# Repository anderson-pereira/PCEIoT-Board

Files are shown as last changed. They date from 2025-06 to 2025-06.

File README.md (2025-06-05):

# PCEIoT-Board V1.1.0

Este repositório contém os arquivos de projeto da placa **PCEIoT V1.1.0**, utilizada como ferramenta didática no curso **Projeto de Circuitos Eletrônicos para IoT**.

Texto alternativo

## Sobre o Curso: Projeto de Circuitos Eletrônicos para IoT

O curso foi concebido para capacitar estudantes de graduação no desenvolvimento de circuitos eletrônicos para aplicações em Internet das Coisas (IoT). O aprendizado abrange desde a **seleção de sensores e componentes** até a **criação e finalização de diagramas esquemáticos** utilizando o software Altium Designer.

Ao longo das aulas, os participantes exploram:

* **Protocolos de comunicação** básicos como I2C, SPI e UART.
* A interpretação de **datasheets** (folhas de dados) dos componentes eletrônicos.
* Habilidades práticas na elaboração de esquemáticos e interfaces para **sensores, botões, LEDs e conectores**.

Com uma abordagem que une teoria e prática, o curso permite a compreensão dos princípios fundamentais do design de circuitos eletrônicos por meio do desenvolvimento de projetos reais, preparando os alunos para os desafios do design de placas de circuito impressos.

## Organização dos Arquivos

Os arquivos do projeto estão estruturados da seguinte forma:

* 📂 `Altium Designer Sources`
    * Contém todos os arquivos fonte (.PcbDoc, .SchDoc, etc.) utilizados no design da PCB no Altium Designer.
* 📄 `Datasheets`
    * Reúne a documentação técnica (datasheets) dos principais componentes eletrônicos empregados na placa.
* 🛠️ `Fabrication and Assembly`
    * Inclui os arquivos de fabricação (Gerbers, NC Drill), esquemáticos em PDF, lista de materiais (BOM - Bill of Materials) e outras informações essenciais para a fabricação e montagem da PCB.

---

### Como Utilizar este Repositório

1.  **Para Estudo:** Explore os esquemáticos e o layout da PCB na pasta `Altium Designer Sources` (requer Altium Designer) ou os PDFs em `Fabrication and Assembly`.
2.  **Para Fabricação:** Utilize os arquivos da pasta `Fabrication and Assembly` para encomendar a fabricação da placa e adquirir os componentes listados na BOM.
3.  **Para Referência:** Consulte os `Datasheets` para entender o funcionamento e as especificações de cada componente.

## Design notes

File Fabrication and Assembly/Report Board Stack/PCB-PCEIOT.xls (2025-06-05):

Board Stack Report
Stack Up |  | Layer Stack
Layer | Board Layer Stack | Name | Material | Thickness | Constant
1 |  | Top Overlay |  | 0mm
2 |  | Top Mask | Solder Resist | 0.03048mm | 3.8
3 |  | Top Copper |  | 0.035mm
4 |  | Dielectric 1 | 7628 | 0.2104mm | 4.4
5 |  | Top Ref |  | 0.0152mm
6 |  | Core | FR-4 | 1.065mm | 4.6
7 |  | Botton Ref |  | 0.0152mm
8 |  | Dielectric 2 | 7628 | 0.2104mm | 4.4
9 |  | Bottom Copper |  | 0.035mm
10 |  | Bottom Mask | Solder Resist | 0.03048mm | 3.8
11 |  | Bottom Overlay |  | 0mm
 | Height : 1.64716mm

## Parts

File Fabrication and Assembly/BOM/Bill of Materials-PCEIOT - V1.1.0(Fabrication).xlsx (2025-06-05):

Quantity | Designator | Comment | Description | Footprint | LibRef
21 | C6, C7, C9, C11, C12, C13, C14, C15, C16, C17, C18, C20, C21, C22, C23, C24, C25, C26, C27, C28, C29 | VJ0603Y104MXJCW1BC | Multilayer Ceramic Capacitor, 0.1 uF, 16 V, ± 20%, X7R, 0603 [1608 Metric] | CAPC0603(1608)100_L | CMP-001-00085-1
17 | R2, R3, R4, R8, R11, R12, R13, R14, R18, R21, R22, R23, R26, R27, R36, R37, R44 | Resistor 10k +/-1% 0603 100 mW | Chip Resistor, 10 KOhm, +/- 1%, 01 W, -55 to 155 degC, 0603 (1608 Metric) | RESC0603(1608)_L | CMP-009-00017-7
6 | R16A, R16B, R16C, R17A, R17B, R17C | ERJ-3EKF1000V | SMD Chip Resistor, 100 Ohm, ï¿½ 1%, 100 mW, 0603 [1608 Metric], Thick Film, Precision | RESC0603(1608)_L | CMP-009-00188-1
5 | R5, R9, R10, R30, R31 | Resistor 0R +/- 5% 0603 100 mW | Chip Resistor, 0 Ohm, 0.1 W, -55 to 155 degC, 0603 (1608 Metric) | RESC0603(1608)_L | CMP-009-00006-6
4 | C1, C4, C5, C19 | VJ0603Y103KXAAC | Multilayer Ceramic Capacitor, 0.01 uF, 50 V, ± 10%, X7R, 0603 [1608 Metric] | CAPC0603(1608)100_L | CMP-001-00084-1
4 | R1, R38, R41, R45 | Resistor 1k +/-1% 0603 100 mW | Chip Resistor, 1 KOhm, +/-1%, 0.1 W, -55 to 155 degC, 0603 (1608 Metric) | RESC0603(1608)_L | CMP-009-00014-6
3 | D2A, D2B, D2C | ASMT-YTB7-0AA02 | LED Tri-Color Blue/Green/Red 469nm/529nm/623nm Chip LED 6-Pin PLCC T/R | FP-PLCC-6-MFG | CMP-007-00036-1
3 | R15A, R15B, R15C | ERJ-3GEYJ301V | Res Thick Film 0603 300 Ohm 5% 1/10W ±200ppm/°C Molded SMD Punched Carrier T/R | RESC0603(1608)_L | CMP-009-00189-1
3 | SW1, SW2, SW3 | FSM4JSMA | Switch Tactile OFF (ON) SPST Round Button Gull Wing 0.05A 12VDC 1.57N SMD Loose Piece | TECO-FSM4JSMA_V | CMP-011-00013-1
2 | C2, C3 | Capacitor 4.7µF +/-20% 10V 0603 | Chip Capacitor, 4.7µF +/-20%, 10V, 0603, Thickness 1 mm | CAPC0603(1608)100_L | CMP-001-00076-4
2 | L1, L2 | BLM21PG331SN1D | IND, Chip Ferrite Bead, 330 Ohm, +/- 25%, 1.5 A, -55 to 125 degC, 0805 (2012 Metric), Tape and Reel | INDC2013X105X50ML20T20 | CMP-006-00000-3
2 | Q1, Q2 | DMN1019USN-7 | N-Channel 12 V 10 mO 50.6 nC SMT Enhancement Mode Mosfet - SC-59 (SOT-23) | FP-SC59-MFG | CMP-013-00035-1
2 | R25, R28 | ERJ-3GEYJ475V | Res Thick Film 0603 4.7M Ohm 5% 0.1W -400ppm/°C to 150ppm/°C Molded SMD Punched Carrier T/R | RESC0603(1608)_L | CMP-009-00185-1
2 | R35, R43 | CRCW06032K20FKEA | SMD Chip Resistor, 2.2 kOhm, ± 1%, 100 mW, 0603 [1608 Metric], Thick Film, General Purpose | RESC0603(1608)_L | CMP-009-00186-1
2 | R39, R40 | Resistor 100k +/-1% 0603 100 mW | Chip Resistor, 100 KOhm, +/- 1%, 0.1 W, -55 to 155 degC, 0603 (1608 Metric) | RESC0603(1608)_L | CMP-009-00023-6
2 | TP1, TP2 | 5003 | Test Point, Orange, Height 4.6 mm, Tail Length 3 mm, 1-Pin THD, RoHS | KSTN-5003 | CMP-002-00037-2
1 | C30 | C0603C101K5GACTU | Multilayer Ceramic Capacitor, 100 pF, 50 V, ï¿½ 10%, C0G (NP0), 0603 [1608 Metric] | CAPC0603(1608)100_L | CMP-001-00088-1
1 | C31 | GRM188R60J106ME47D | Multilayer Ceramic Capacitor, 10 uF, 6.3 V, ± 20%, X5R, 0603 [1608 Metric] | CAPC0603(1608)100_L | CMP-001-00087-1
1 | DS1 | 19-217/R6C-AL1M2VY/3T | Chip LED, Red, 5 V, 25 mA, -40 to 85 degC, 2-Pin SMD (0603), RoHS, Tape and Reel | EVRL-0603-2_V | CMP-007-00004-2
1 | J3 | 640456-2 | Connector 250V AC/DC 5A 2P 1 Row PCB - Vertical Mounting Polyester White | TECO-640456-2_V | CMP-002-00073-1
1 | MK1 | CMEJ-0415-42-LP | 4.0 mm, Omnidirectional, PCB Mount, 2.0 Vdc, Elecret Condenser Microphone | MIC_CMEJ-0415-42-LP | CMP-010-000001-2
1 | P1 | 22-28-4033 | KK 254 Breakaway Header Vertical 3 Circuits 0.38um Gold Selective Plating Mating Pin 6.09mm | MOLX-22-28-4033_V | CMP-002-00076-1
1 | Q3 | G09P02L | P-Channel Enhancement Mode Power MOSFET | G09P02L | CMP-013-00036-1
1 | R32 | ERJ-3EKF2001V | SMD Chip Resistor, 2 kOhm, ï¿½ 1%, 100 mW, 0603 [1608 Metric], Thick Film, Precision | RESC0603(1608)_L | CMP-009-00181-1
1 | R33 | CRCW0603470RJNEA | Res Thick Film 0603 470 Ohm 5% 0.1W(1/10W) ±200ppm/°C Pad SMD Automotive T/R | RESC0603(1608)_L | CMP-009-00182-1
1 | R34 | ERJ-3EKF3300V | SMD Chip Resistor, 330 Ohm, ± 1%, 100 mW, 0603 [1608 Metric], Thick Film, Precision | RESC0603(1608)_L | CMP-009-00184-1
1 | R42 | TC33X-2-104E | Cermet trimmer potentiometer, 100 kΩ, 0.1 W, SMD, on top, TC33X-2-104E | FP-TC33X-2-MFG | CMP-009-00187-1
1 | SKT1 | 5033981892 | Micro SD Card Connector, Pitch 1.1 mm, 8 Position, Height 1.4 mm, -25 to 85 degC, RoHS, Tape and Reel | MOLX-5033981892_V | CMP-002-00049-5
1 | U1 | OPT4001DTSR | High-speed high-precision digital ambient light sensor (ALS) 8-SOT-5X3 -40 to 85 | SON50P130X60-8N | CMP-010-00031-2
1 | U2 | SHT40I-AD1B-R3 | Humidity And Temperature Sensor | QFN80P150X150X55-4N | CMP-010-00033-3
1 | U3 | ICM-42670-P | Mems Module, 1.71-3.6 V, Lga-14 Rohs Compliant: Yes | QFN50P300X250X81-14N | CMP-010-00032-3
1 | U4 | SX1509BIULTRT | IC Gpio Expander I2C 16CH 28QFN / I2C Interface 5.5V 28-PIN Qfn-ut Ep T/r | QFN40P410X410X60_HS-29N | CMP-016-00011-5
1 | U5 | MS563702BA03-50 | Pressure Sensor, Barometric, 300 mbar, 1200 mbar, QFN, 8, -40 C | FP-MS563702BA03-50-MFG | CMP-010-00027-2
1 | U6 | LM4040DYM3-2.5-TR | LM4040 Series 2.5 V ±1 % Precision Micropower Shunt Voltage Reference - SOT-23 | FP-SOT23-3LD-PL-1-IPC_A | CMP-004-00033-1
1 | U7 | SC0918 | Raspberry Pi Pico W RP2040 | MODULE_SC0918 | CMP-006-000001-6
1 | U8 | MAX4466EXK-T | Audio Amp Microphone 1-CH Mono Class-AB 5-Pin SC-70 T/R | SOT65P200X110-5N | CMP-00027-00002-4
1 | U9 | MCP73831T-2ACI/OT | MCP73831 Series Single-Cell Li-Ion/Li-Polymer Battery Charge Controller SOT-23-5 | FP-C04-091-OT-MFG | CMP-001-0001-1
1 | U10 | BQ29700DSER | Li-Ion/Li Polymer Advanced Single-Cell Battery Protector IC Family 6-WSON -40 to 85 | FP-DSE0006A-MFG | CMP-001-0002-1

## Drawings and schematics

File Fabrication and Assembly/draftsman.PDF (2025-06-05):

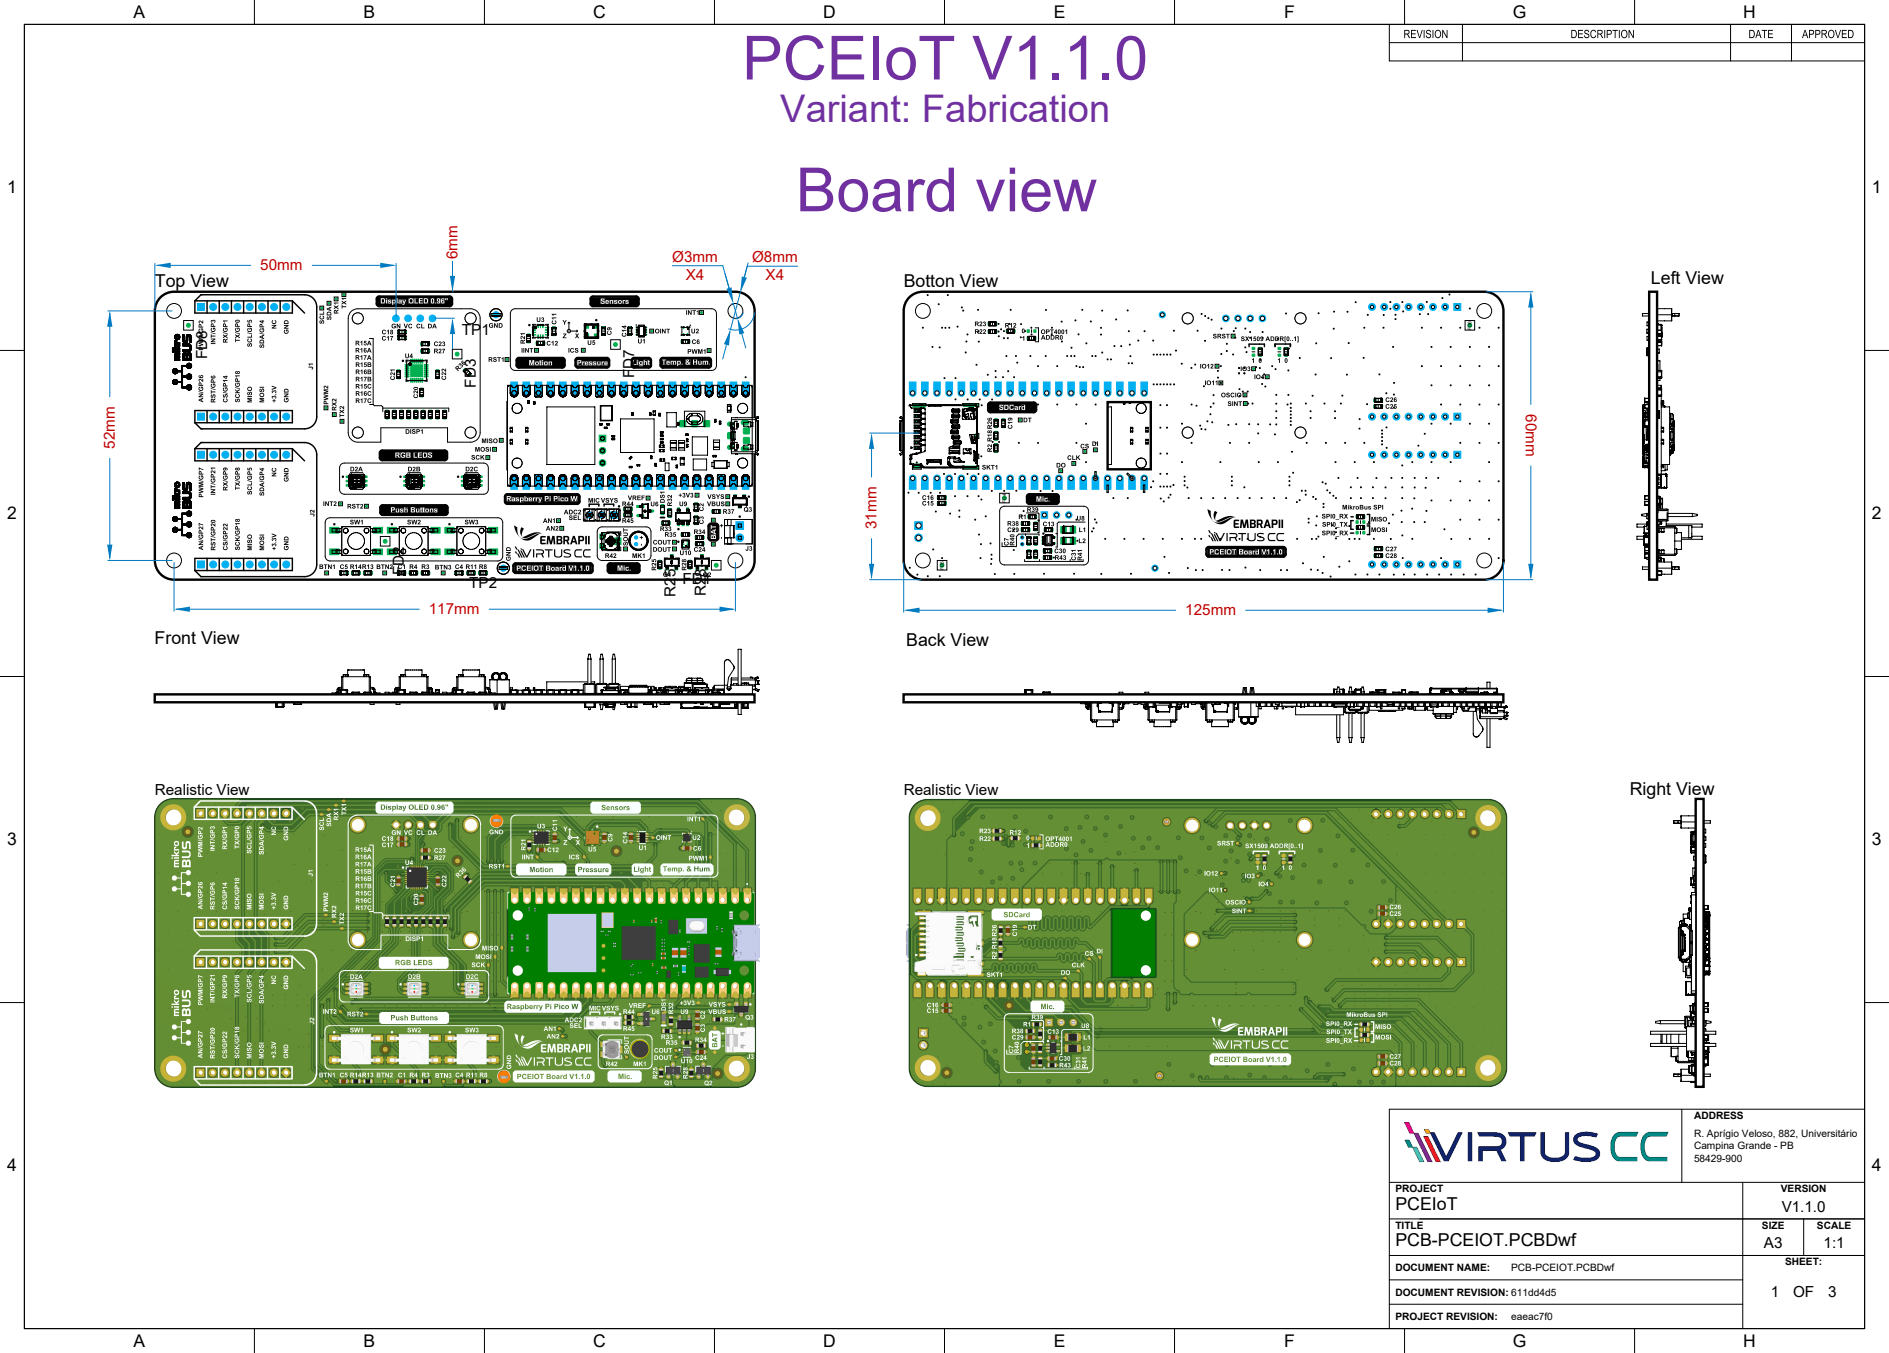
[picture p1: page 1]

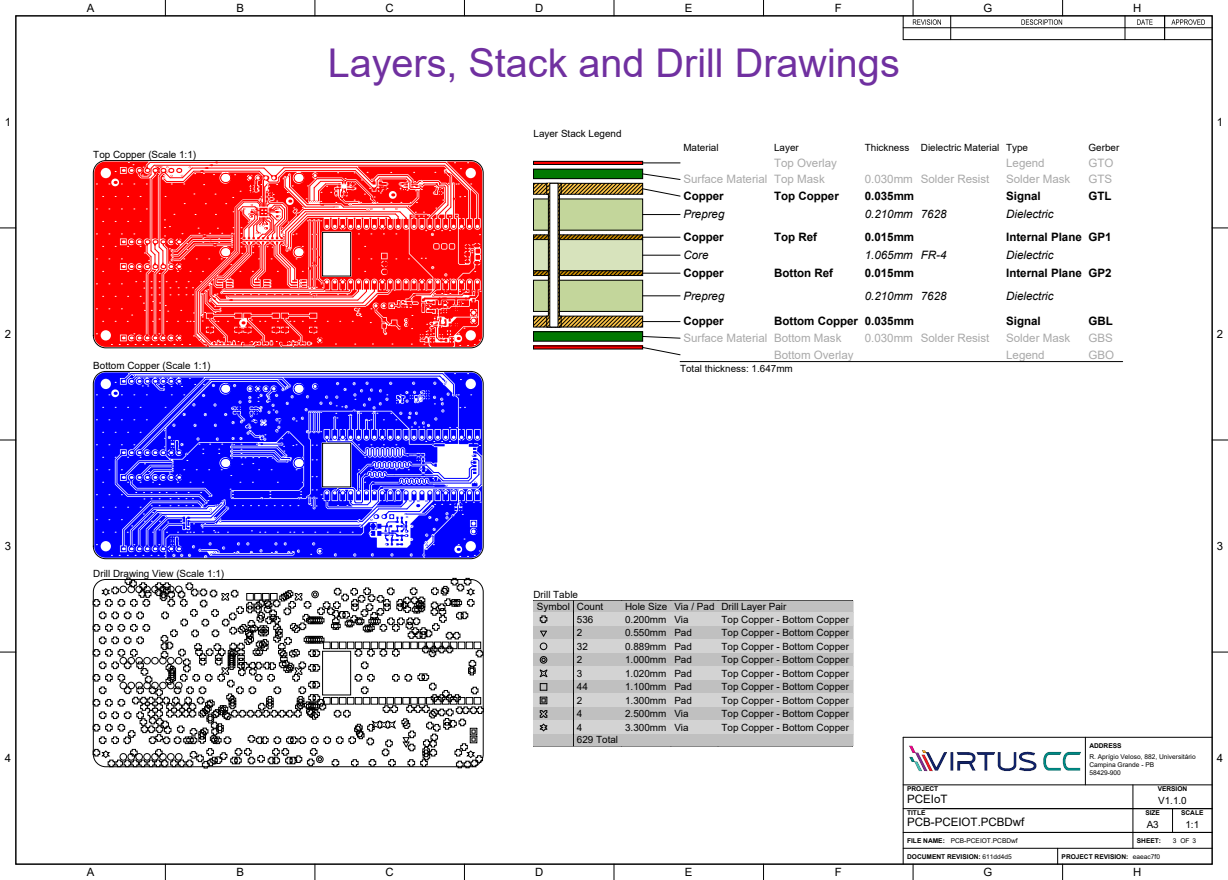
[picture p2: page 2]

Layers, Stack and Drill Drawings

Drill Drawing View (Scale 1:1)

Drill Layer Pair
Top Copper - Bottom Copper

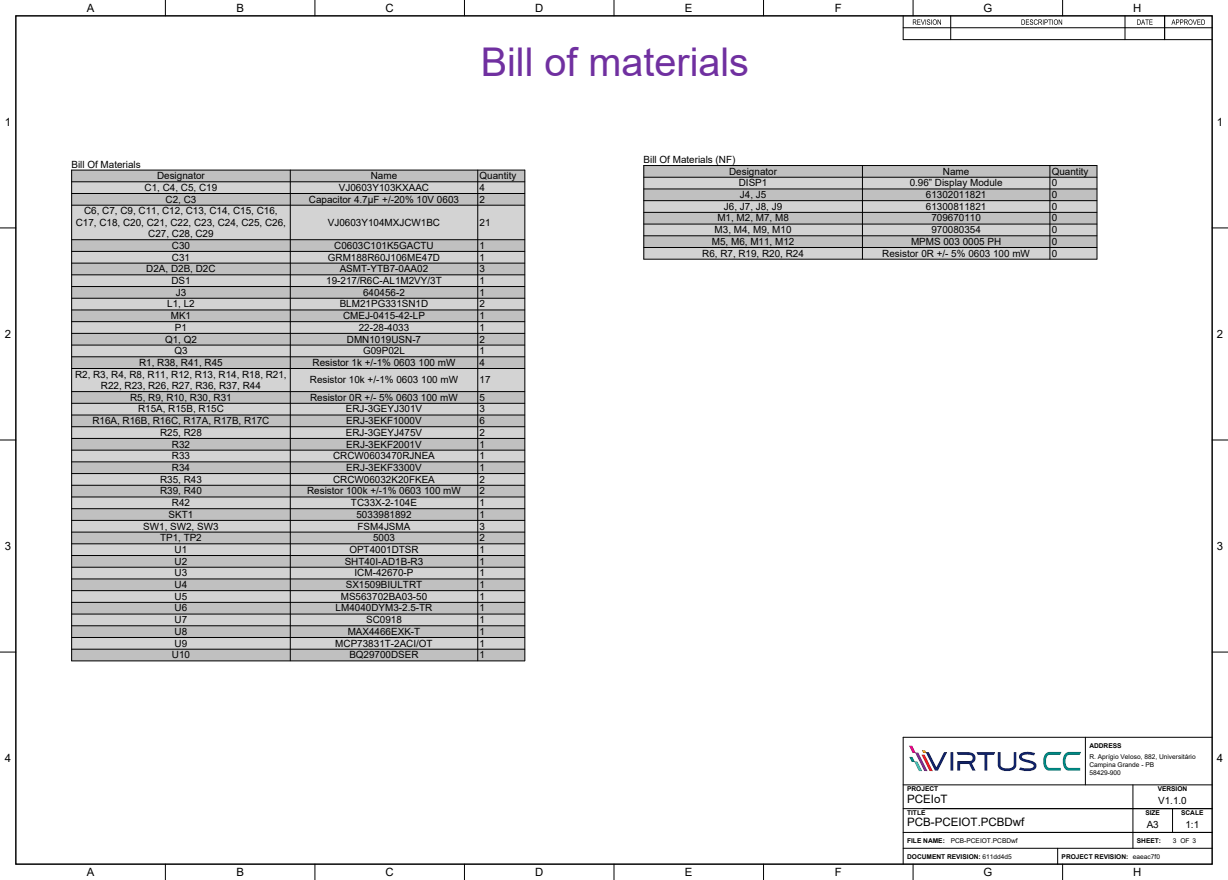
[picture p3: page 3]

Bill Of Materials (NF)

Designator | Name | Quantity
C1, C4, C5, C19 | VJ0603Y103KXAAC | 4
C2, C3 | Capacitor 4.7µF +/-20% 10V 0603 | 2

DISP1 | 0.96” Display Module | 0
J4, J5 | 61302011821 | 0
J6, J7, J8, J9 | 61300811821 | 0
M1, M2, M7, M8 | 709670110 | 0
M3, M4, M9, M10 | 970080354 | 0
M5, M6, M11, M12 | MPMS 003 0005 PH | 0
R6, R7, R19, R20, R24 | Resistor 0R +/- 5% 0603 100 mW | 0

C6, C7, C9, C11, C12, C13, C14, C15, C16, C17, C18, C20, C21, C22, C23, C24, C25, C26, C27, C28, C29 | VJ0603Y104MXJCW1BC | 21

C30 | C0603C101K5GACTU | 1
C31 | GRM188R60J106ME47D | 1
D2A, D2B, D2C | ASMT-YTB7-0AA02 | 3
DS1 | 19-217/R6C-AL1M2VY/3T | 1
J3 | 640456-2 | 1
L1, L2 | BLM21PG331SN1D | 2
MK1 | CMEJ-0415-42-LP | 1
P1 | 22-28-4033 | 1
Q1, Q2 | DMN1019USN-7 | 2
Q3 | G09P02L | 1

R1, R38, R41, R45 | Resistor 1k +/-1% 0603 100 mW | 4

R2, R3, R4, R8, R11, R12, R13, R14, R18, R21, R22, R23, R26, R27, R36, R37, R44 | Resistor 10k +/-1% 0603 100 mW | 17

R5, R9, R10, R30, R31 | Resistor 0R +/- 5% 0603 100 mW | 5
R15A, R15B, R15C | ERJ-3GEYJ301V | 3

R16A, R16B, R16C, R17A, R17B, R17C | ERJ-3EKF1000V | 6

R25, R28 | ERJ-3GEYJ475V | 2
R32 | ERJ-3EKF2001V | 1
R33 | CRCW0603470RJNEA | 1
R34 | ERJ-3EKF3300V | 1
R35, R43 | CRCW06032K20FKEA | 2
R39, R40 | Resistor 100k +/-1% 0603 100 mW | 2
R42 | TC33X-2-104E | 1
SKT1 | 5033981892 | 1
SW1, SW2, SW3 | FSM4JSMA | 3
TP1, TP2 | 5003 | 2
U1 | OPT4001DTSR | 1
U2 | SHT40I-AD1B-R3 | 1
U3 | ICM-42670-P | 1
U4 | SX1509BIULTRT | 1
U5 | MS563702BA03-50 | 1
U6 | LM4040DYM3-2.5-TR | 1
U7 | SC0918 | 1
U8 | MAX4466EXK-T | 1
U9 | MCP73831T-2ACI/OT | 1
U10 | BQ29700DSER | 1

ADDRESS R. Aprígio Veloso, 882, Universitário Campina Grande - PB 58429-900

PROJECT PCEIoT | VERSION V1.1.0
TITLE PCB-PCEIOT.PCBDwf | SIZE A3 | SCALE

FILE NAME: PCB-PCEIOT.PCBDwf | 3 3

DOCUMENT REVISION: 611dd4d5 | PROJECT REVISION: eaeac7f0
